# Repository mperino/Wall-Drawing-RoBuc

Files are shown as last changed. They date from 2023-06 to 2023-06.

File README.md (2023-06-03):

# Wall Drawing RoBuc

For FRC 2023-24 "Crescendo", I want to make a wall drawing robot that is capable of using both a marker and a spray can to make art live.  3D printed, read from SD card, powerfull steppers, stepper based pen (not servo) and with LED status lights to tell what color marker to load next.  My implementation is based on Fumik Robot, with a re-design of the Robot platform.  First Version will be a modified version of the Fumik code, with later versions being a complete re-write.
<br>
New Hardware Design:
https://a360.co/45KpkjN
<br>
<p>Front:
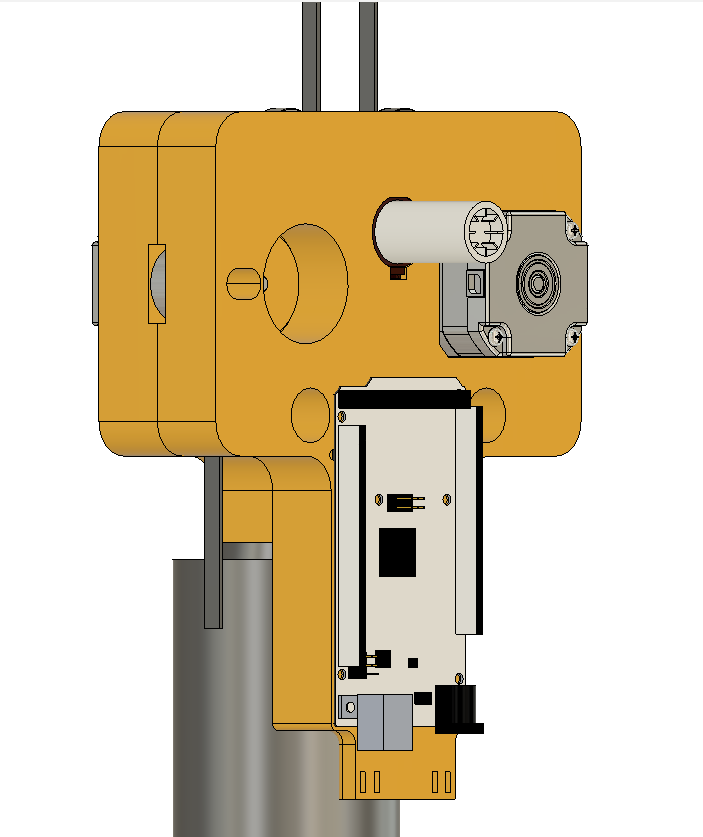
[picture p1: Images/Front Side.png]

</p>
<p>Back:
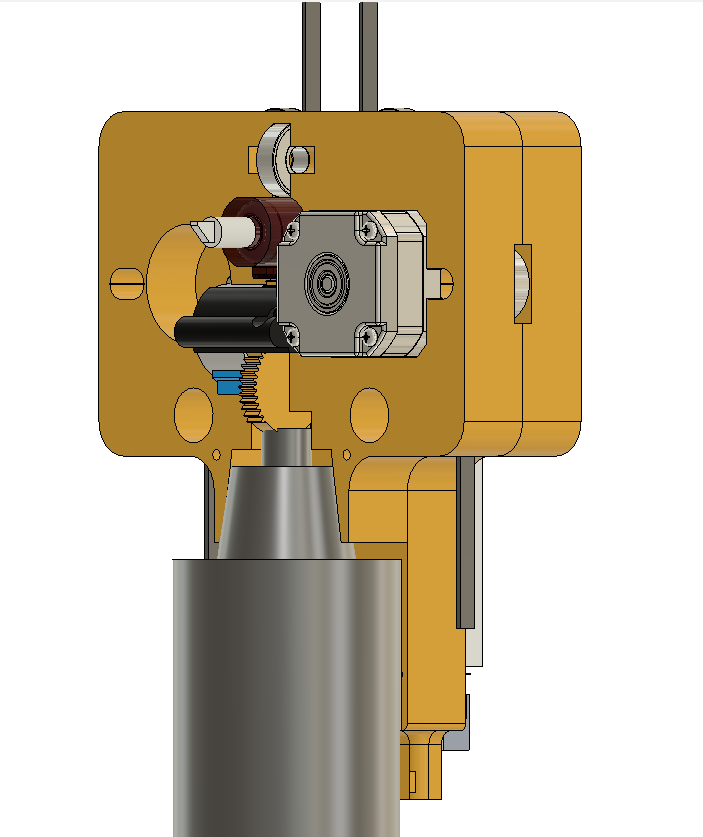
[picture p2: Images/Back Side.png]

</p>
<p> Inside:
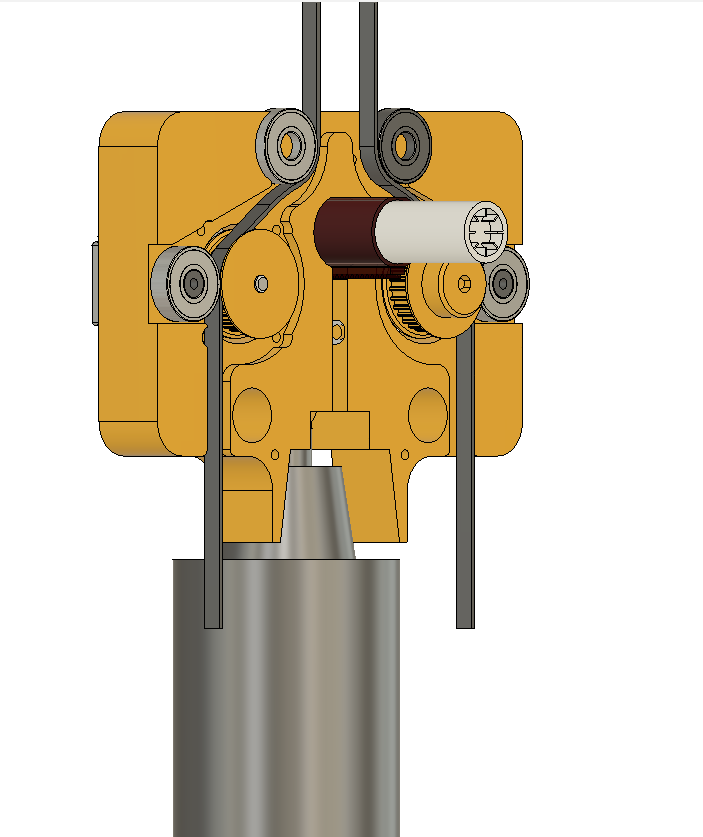
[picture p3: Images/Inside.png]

</p>
<br>

<br>
<hr>
The orignal Fumik code and instructions:
Visit the original Fumik at https://www.fumik.com/ 
<BR>
Fumik Arduino code for robot is at: https://github.com/fumikrobot/source-code/blob/main/fumik_rv9.ino
<p align="center">
  
</p>
<u><b> How to start a picture: </b></u>
<br/>
3.1 Your Picture need to draw
3.2 Convert picture to vector (*.svg file) by CorelDraw (or any other software support *.svg file)
<br/>
(see sample file test.cdr -> test.svg at https://github.com/fumikrobot/source-code/tree/main/draw%20file%20prepare)

3.3 Convert vector file to code for Arduino (by MS Excel, download at https://github.com/fumikrobot/source-code/blob/main/draw%20file%20prepare/SVG%20code%20extract.xlsm)

3.4 Copy code file to SD card
(sample file draw.txt at https://github.com/fumikrobot/source-code/blob/main/draw%20file%20prepare/draw.txt)

3.5 Plug in SD card to robot and start drawing
<br/><br/><br/><br/>
You can support and purchase the original at:
The robot can help us to make drawing on wall for fun or decoration. You can use robot as gift or STEM KIT for education for your kid, or student, hobbies need to understand about wall drawing robot.
<br/><br/>
Crowfunding at https://igg.me/at/fumik-robot
<br/>

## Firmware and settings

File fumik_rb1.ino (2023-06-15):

//Wall drawing RoBuc 
//Based on code from fumik.com - mail baank83@gmail.com
//Original Author: Nguyen Huu Phuc - 2022/May. All rights reserved.
//Wall RoBuc by Mark Perino mark.perino@gmail.com
//This code for Arduino MEGA, SD card

// Version 0.1, Code Status (partially working)
// LED code works
// M150 Rxxx Gxxx Bxxx Ixxx added
// Code Mode Switches work
// interactive works with move_pen_abs()


#include <AccelStepper.h>
#include <SD.h>                 // for SD card
#define SD_ChipSelectPin 53     // for SD card
File myFile;                    // for SD card
#include <Servo.h>              // for servo pen              
Servo pen_servo;               // for servo pen
#include <Adafruit_NeoPixel.h> // for neopixel ring
#define LED_PIN   49
// How many NeoPixels are attached to the Arduino?
#define LED_COUNT 12
// Declare our NeoPixel strip object:
Adafruit_NeoPixel strip(LED_COUNT, LED_PIN, NEO_GRB + NEO_KHZ800);

//how long to debounce]
#define DEBOUNCE_SLEEP

// Code Mode Switches
// 2 wired switches control the starting mode of the robot.
// First switch controls the command_mode: GCODE (new limitied) or FUNCTION COMMAND (original drawing mode)
// Secong switch controls if the action_mode is INTERACTIVE(new serial like grbl) or FILE (read draw.txt or draw.gcode)
#define COMMAND_MODE_PIN 45
#define ACTION_MODE_PIN 47
int command_state = 0;
int action_state = 0;
//stepper based PEN settings
//define Pen Load and Unload switches (Momentary Buttons)
#define PEN_LOAD_PIN 43
#define PEN_UNLOAD_PIN 42
#define PEN_LOAD_DISTANCE 100
#define PEN_UNLOAD_DISTANCE 200
int pen_load_state = 1;


const int dirPin_c = 7;
const int stepPin_c = 4;
const int dirPin_a = 5;
const int stepPin_a = 2;
const int dirPin_p = 6;   //drive for pen
const int stepPin_p = 3;  //drive for pen
const int enPin = 8;
#define motorInterfaceType 1

AccelStepper stepper_a(motorInterfaceType, stepPin_a, dirPin_a);
AccelStepper stepper_c(motorInterfaceType, stepPin_c, dirPin_c);
AccelStepper stepper_p(motorInterfaceType, stepPin_p, dirPin_p);

long steps_a, steps_c; //curent step of a, c
float a, c, a_0, c_0; //unit mm
float a_dev, c_dev; //deviation value of a, c
float pen_x, pen_y; //coordinate of pen, unit mm
float s_a, s_c, s_a_run, s_c_run; //steps for a, c
float pen_x0, pen_y0, pen_x0_next, pen_y0_next, svg_x0, svg_y0;
float x_ratio, y_ratio, x_angle, y_angle;
float draw_res; //draw resolution
float w2y, p;

float g1, g2, step1, step2, r1, r2;
float stepper_speed, basic_speed, by_stepper_speed;

boolean pen_pos;  //false = pen at open position; true = pen at write position

String draw_command;

void setup() {
  // setup Serial Port 
  Serial.begin(9600);
  
  // setup Pixel Ring
  Serial.println("Clearing LED Ring");
  strip.begin();
  strip.show(); // Initialize all pixels to 'off'
  strip.setPixelColor(1, 0, 50, 0);
  strip.show(); // set green pixel status
  
  // setup servos and motion parameters
  pen_servo.attach (11); //servo motor is connected to pin 11 Arduino Mega ~ (Z+ End Stop) of Arduino cnc Shield
  pinMode(enPin, OUTPUT);
  stepper_speed = 250; //unit steps/sec for main steppers
  by_stepper_speed = 250; //unit steps /sec for BY stepper
  basic_speed = 250;   //unit steps/sec; note: high speed + low resolution (draw_res) will make vibration
  stepper_a.setMaxSpeed(2000);
  stepper_a.setAcceleration(200000);  //set to max
  stepper_a.setSpeed(stepper_speed);
  
  stepper_c.setMaxSpeed(2000);
  stepper_c.setAcceleration(200000);  //set to max
  stepper_c.setSpeed(stepper_speed);

  stepper_p.setMaxSpeed(2000); //max 550
  stepper_p.setAcceleration(200000);
  stepper_p.setSpeed(by_stepper_speed);

  g1 = 63.68; //gear ratio
  g2 = g1;
  step1 = 32; //step/rev (full-step mode: 32; half-step mode: 64)
  step2 = step1;
  r1 = 9.5; //radius of wheel mm
  r2 = 9.5;
  a = 0;
  c = 0;

  p = 3190;   //mm, distance pin_a to pin_c (horizontal direction) 1600
  w2y = 40;  //mm, distance pin_a to pin_c (vertical direction)  4
 
  // zero position of pen must be same as in real model
  pen_x0 = 400;  //mm, computer room: 390-400-310
  pen_y0 = 700;  //mm, computer room: 900-700-410
                 //y0 under real -> C-curve up (u)
                 //y0 over real -> C-curve down (n)

  x_ratio = 1.0;  //adjust to change ratio of picture in x_axis
  y_ratio = 1.0;  //adjust to change ratio of picture in y_axis

  draw_res = 0.7; //mm, draw resolution is 0.7mm (high number -> high draw speed + low resolution)

  x_angle = -1.43; //degree, effect to rotation of picture in x_axis
  x_angle = radians(x_angle);

  y_angle = -0.36;  //degree, effect to rotation of picture in y_axis
  y_angle = radians(y_angle);

  pen_servo.write(50);  //set pen at open position, to make sure pen at open position
  pen_pos = false;      //now pen at open position, init pen_pos = "false"


  // which modes are we in Function Command vs Gcode, and INteractive vs. File
  pinMode(COMMAND_MODE_PIN, INPUT); // set defined pins to input
  pinMode(ACTION_MODE_PIN, INPUT); // set defined pins to input
  command_state = digitalRead(COMMAND_MODE_PIN);
  action_state = digitalRead(ACTION_MODE_PIN);
  if (command_state == HIGH) {
    Serial.println("Command Mode is GCODE");
    strip.setPixelColor(2, 0, 50, 0);
    strip.show(); // set pixel 2 to green aka gcode
  }
  else {
    Serial.println("Command Mode is Function Command. Aka original");
    strip.setPixelColor(2, 254, 119, 254);
    strip.show(); // set pixel 2 to Fuscia aka Function
  }
  if (action_state == HIGH) {
    Serial.println("Action Mode is Interactive");
    strip.setPixelColor(3, 5, 0, 50);
    strip.show(); // set pixel 3 to Indigo aka Interactive
  }
  else {
    Serial.println("Action Mode is File. draw.txt or draw.gcode will be used");
    strip.setPixelColor(3, 254, 119, 254);
    strip.show(); // set pixel 3 to Fuscia aka File
  }
  if (action_state == LOW) {
    // check if SD card mounted or not
    if (!SD.begin(SD_ChipSelectPin)) {  // see if the card is present and can be initialized:
      Serial.println("SD fail");
      return;   // don't do anything more if not
    }
    else{   
      Serial.println("---------------------------->>>>>>>-------SD card ok");
    }
    delay(200);
    myFile = SD.open("draw.txt");
    if (myFile) Serial.println("the file is opened OK");
    else Serial.println("error opening draw.txt");
  }
  else {
    Serial.println("Interactive Mode Setup.  Press Any Key to continue.");
    while (Serial.available() == 0) {
          }
    Serial.println("Entering Command Loop..");
  }
delay(10000);

}

void loop() {
    digitalWrite(enPin, LOW);  //enable stepper motor
    
    pen_write_pos();
    delay(1000);
    pen_open_pos();
    delay(1000);
          
    svg_x0 = 0;
    svg_y0 = 0;
  
    // declare a_0, c_0 at x0,y0
    find_a_c(pen_x0, pen_y0);
    a_0 = a;  //zero position
    c_0 = c;  //zero position
  
    pen_x0_next = pen_x0;
    pen_y0_next = pen_y0;

    while (action_state == HIGH) {
      Serial.println("Your Command?: ");
      while (Serial.available() == 0) {   
      }
      draw_command = Serial.readString();
      draw_command.trim();
      execute_command(draw_command);
    }

    // Reading the file
    String draw_command, string_result;
    char char_temp = '0';

    myFile = SD.open("draw.txt");

    // variables for draw
    float x1, x2, x3, x4, y1, y2, y3, y4;

    while(1){
      if (myFile) draw_command = read_until('(');
      else  Serial.println("error opening draw.txt");
  
      if (draw_command == "move_pen_abs("){
        string_result = read_until(',');  //continue reading file unit character ','
        string_result = string_result.substring(0,string_result.length()-1);  //will delete last character, it is ','
        x1 = string_result.toFloat();
        string_result = read_until(')');  //continue reading file unit character ')'
        string_result = string_result.substring(0,string_result.length()-1);  //will delete last character, it is ')'
        y1 = string_result.toFloat();
        move_pen_abs(x1,y1);  //move pen absolute to x1,y1
  
        //Serial.println(draw_command);
        //Serial.println(x1);
        //Serial.println(y1);
      }
      
      if (draw_command == "draw_curve("){
        string_result = read_until(',');  //continue reading file unit character ','
        string_result = string_result.substring(0,string_result.length()-1);  //will delete last character, it is ','
        x1 = string_result.toFloat();
        string_result = read_until(',');  //continue reading file unit character ')'
        string_result = string_result.substring(0,string_result.length()-1);  //will delete last character, it is ')'
        y1 = string_result.toFloat();
  
        string_result = read_until(',');  //continue reading file unit character ','
        string_result = string_result.substring(0,string_result.length()-1);  //will delete last character, it is ','
        x2 = string_result.toFloat();
        string_result = read_until(',');  //continue reading file unit character ')'
        string_result = string_result.substring(0,string_result.length()-1);  //will delete last character, it is ')'
        y2 = string_result.toFloat();
  
        string_result = read_until(',');  //continue reading file unit character ','
        string_result = string_result.substring(0,string_result.length()-1);  //will delete last character, it is ','
        x3 = string_result.toFloat();
        string_result = read_until(',');  //continue reading file unit character ')'
        string_result = string_result.substring(0,string_result.length()-1);  //will delete last character, it is ')'
        y3 = string_result.toFloat();
  
        string_result = read_until(',');  //continue reading file unit character ','
        string_result = string_result.substring(0,string_result.length()-1);  //will delete last character, it is ','
        x4 = string_result.toFloat();
        string_result = read_until(')');  //continue reading file unit character ')'
        string_result = string_result.substring(0,string_result.length()-1);  //will delete last character, it is ')'
        y4 = string_result.toFloat();
  
        draw_curve(x1,y1,x2,y2,x3,y3,x4,y4);
        /*
        Serial.println(draw_command);
        Serial.println(x1);
        Serial.println(y1);
        Serial.println(x2);
        Serial.println(y2);
        Serial.println(x3);
        Serial.println(y3);
        Serial.println(x4);
        Serial.println(y4);
        */
      }
  
      if (draw_command == "draw_line("){
        string_result = read_until(',');  //continue reading file unit character ','
        string_result = string_result.substring(0,string_result.length()-1);  //will delete last character, it is ','
        x1 = string_result.toFloat();
        string_result = read_until(',');  //continue reading file unit character ')'
        string_result = string_result.substring(0,string_result.length()-1);  //will delete last character, it is ')'
        y1 = string_result.toFloat();
  
        string_result = read_until(',');  //continue reading file unit character ','
        string_result = string_result.substring(0,string_result.length()-1);  //will delete last character, it is ','
        x2 = string_result.toFloat();
        string_result = read_until(')');  //continue reading file unit character ')'
        string_result = string_result.substring(0,string_result.length()-1);  //will delete last character, it is ')'
        y2 = string_result.toFloat();
  
        draw_line(x1,y1,x2,y2);
        //Serial.println(draw_command);
        //Serial.println(x1);
        //Serial.println(y1);
        //Serial.println(x2);
        //Serial.println(y2);
      }
  
      if (draw_command == "move_pen_rel("){
        string_result = read_until(',');  //continue reading file unit character ','
        string_result = string_result.substring(0,string_result.length()-1);  //will delete last character, it is ','
        x1 = string_result.toFloat();
        string_result = read_until(')');  //continue reading file unit character ')'
        string_result = string_result.substring(0,string_result.length()-1);  //will delete last character, it is ')'
        y1 = string_result.toFloat();
  
        move_pen_rel(x1,y1);
        //Serial.println(draw_command);
        //Serial.println(x1);
        //Serial.println(y1);
      }
  
      if (draw_command == "endfile(")  break;
  
      
      for (int i=0;i<3;i++){
        myFile.read();  //go through letter ';' and new line -> next reading is next command
      }
    }

  return_home();
  while(1){
    //stop here
    delay(5000);
    //digitalWrite(enPin, HIGH);  //un-enable stepper motor
  }
}


//======================================================SUB PROGRAM====================================
void execute_command(String draw_command) {
  // variables for draw
  float x1, y1, x2, y2;
  if (draw_command.startsWith("move_pen_abs")){
    String values = draw_command.substring(draw_command.indexOf("\(")+1, draw_command.indexOf("\)"));
    String x1v = values.substring(0,values.indexOf(","));
    x1 = x1v.toFloat();
    String y1v = values.substring(values.indexOf(",")+1,values.length());
    y1 = y1v.toFloat();
    move_pen_abs(x1,y1);  //move pen absolute to x1,y1
  //  Serial.println(draw_command);
  //  Serial.println(x1);
  //  Serial.println(y1);
  }

  if (draw_command.startsWith("endfile")){
    Serial.println("Reached File End");
  }

  if (draw_command.startsWith("draw_line")){
    String values = draw_command.substring(draw_command.indexOf("\(")+1, draw_command.indexOf("\)"));
    String x1v = values.substring(0,values.indexOf(","));
    x1 = x1v.toFloat();
    values = values.substring(",");
    String y1v = values.substring(0,values.indexOf(","));
    y1 = y1v.toFloat();
    values = values.substring(",");
    String x2v = values.substring(0,values.indexOf(","));
    x2 = x2v.toFloat();
    values = values.substring(",");
    String y2v = values.substring(0,values.indexOf(","));
    y2 = y2v.toFloat();
    Serial.println(draw_command);
    Serial.println(x1);
    Serial.println(y1);
    Serial.println(x2);
    Serial.println(y2);
    draw_line(x1,y1,x2,y2);  //move pen absolute to x1,y1
  }

  if (draw_command.startsWith("draw_curve")){
    String values = draw_command.substring(draw_command.indexOf("\(")+1, draw_command.indexOf("\)"));
    String pv = values.substring(0,values.indexOf(","));
    float p0x = pv.toFloat();
    values = values.substring(",");
    pv = values.substring(0,values.indexOf(","));
    float p0y = pv.toFloat();
    values = values.substring(",");
    pv = values.substring(0,values.indexOf(","));
    float p1x = pv.toFloat();
    values = values.substring(",");
    pv = values.substring(0,values.indexOf(","));
    float p1y = pv.toFloat();
    values = values.substring(",");
    pv = values.substring(0,values.indexOf(","));
    float p2x = pv.toFloat();
    values = values.substring(",");
    pv = values.substring(0,values.indexOf(","));
    float p2y = pv.toFloat();
    values = values.substring(",");
    pv = values.substring(0,values.indexOf(","));
    float p3x = pv.toFloat();
    values = values.substring(",");
    pv = values.substring(0,values.indexOf(","));
    float p3y = pv.toFloat();
    Serial.println(draw_command);
    Serial.println(p0x);
    Serial.println(p0y);
    Serial.println(p1x);
    Serial.println(p1y);
    Serial.println(p2x);
    Serial.println(p2y);
    Serial.println(p3x);
    Serial.println(p3y);
    draw_curve(p0x, p0y, p1x, p1y, p2x, p2y, p3x, p3y);  //draw the curve
  }

  if (draw_command.startsWith("set_home")){
    String values = draw_command.substring(draw_command.indexOf("\(")+1, draw_command.indexOf("\)"));
    String x1v = values.substring(0,values.indexOf(","));
    x1 = x1v.toInt();
    values = values.substring(",");
    String y1v = values.substring(0,values.indexOf(","));
    y1 = y1v.toInt();
    Serial.println(draw_command);
    Serial.println(x1);
    Serial.println(y1);
    set_home(x1,y1);  //Set Starting Co-ordinate
  }

  if (draw_command.startsWith("set_box_size")){
    String values = draw_command.substring(draw_command.indexOf("\(")+1, draw_command.indexOf("\)"));
    String x1v = values.substring(0,values.indexOf(","));
    x1 = x1v.toInt();
    values = values.substring(",");
    String y1v = values.substring(0,values.indexOf(","));
    y1 = y1v.toInt();
    Serial.println(draw_command);
    Serial.println(x1);
    Serial.println(y1);
    set_box_size(x1,y1);  //Set Starting Co-ordinate
  }

  if (draw_command.startsWith("M150")){
    String values = draw_command.substring(draw_command.indexOf("\(")+1, draw_command.indexOf("\)"));
    String rs = values.substring(values.indexOf("R")+1);
    rs = rs.substring(0,rs.indexOf(" "));
    int red = rs.toInt();
    String gr = values.substring(values.indexOf("G")+1);
    gr = gr.substring(0,gr.indexOf(" "));
    int green = gr.toInt();
    String bl = values.substring(values.indexOf("B")+1);
    bl = bl.substring(0,gr.indexOf(" "));
    int blue = bl.toInt();
    String pi = values.substring(values.indexOf("I")+1);
    pi = pi.substring(0,gr.indexOf(" "));
    int pixel = pi.toInt();
    set_rgb_color(pixel, red, green, blue);

  //  Serial.println(draw_command);
  //  Serial.println(x1);
  //  Serial.println(y1);
  }
}
void set_rgb_color(int pixel, int red, int green, int blue){
  strip.setPixelColor(pixel, red, green, blue);
  strip.show();
}

void set_ring_color(int pixels, int r, int g, int b){
  for (int pix =0; pix <= pixels; pix++) {
    set_rgb_color(pix, r, g, b);
  }
}

void set_box_size(int wide, int tall){
  p = wide;   //mm, distance pin_a to pin_c (horizontal direction) 1600
  w2y = tall;  //mm, distance pin_a to pin_c (vertical direction)  4
}

void set_home(int x0, int y0){
  pen_x0 = x0;  //mm
  pen_y0 = y0;  //mm
}

void change_pen(int R, int G, int, int B){
  //unload Pen
  //loop
  set_ring_color(LED_COUNT,R,G,B);
  // check input
  // debounce
}

void move_a_c(float s1, float s2){
  int stepper_a_speed, stepper_c_speed; //unit steps/sec

  // Set the current position to 0:
  stepper_a.setCurrentPosition(0);
  stepper_c.setCurrentPosition(0);
  
  if(abs(s1)>=abs(s2)){
    if(s1<0) {stepper_a_speed = basic_speed;} //speed pos: motor a makes robot move up
    else stepper_a_speed = -basic_speed;      //speed neg: motor a makes robot move down

    if(s2<0) {stepper_c_speed = -abs(s2/s1)*basic_speed;}  //speed pos: motor c makes robot move down
    else stepper_c_speed = abs(s2/s1)*basic_speed;         //speed neg: motor c makes robot move up
  }
  else{
    if(s2<0) {stepper_c_speed = -basic_speed;}  //speed pos: motor c makes robot move down
    else stepper_c_speed = basic_speed;         //speed neg: motor c makes robot move up

    if(s1<0) {stepper_a_speed = abs(s1/s2)*basic_speed;}    //speed pos: motor a makes robot move up
    else stepper_a_speed = -abs(s1/s2)*basic_speed;         //speed neg: motor a makes robot move down
  }


  if (abs(stepper_a_speed) < 5){
    if (stepper_a_speed < 0) stepper_a_speed = -5;
    else stepper_a_speed = 5;
  }
  if (abs(stepper_c_speed) < 5){
    if (stepper_c_speed < 0) stepper_c_speed = -5;
    else stepper_c_speed = 5;
  }
  /*

  Serial.print("stepper_a_speed = ");
  Serial.println(stepper_a_speed);
  Serial.print("stepper_c_speed = ");
  Serial.println(stepper_c_speed);
  Serial.print("s1 = ");
  Serial.println(s1);
  Serial.print("s2 = ");
  Serial.println(s2);
  */
  

  // Run the motor
  while((abs(stepper_a.currentPosition()) < abs((long)s1))||(abs(stepper_c.currentPosition()) < abs((long)s2)))
  {
    stepper_a.setSpeed(stepper_a_speed); //speed pos: motor a makes robot move up; 
    if((abs(stepper_a.currentPosition()) < abs((long)s1))) {stepper_a.runSpeed();}
    
    stepper_c.setSpeed(stepper_c_speed); //speed pos: motor c makes robot move down
    if((abs(stepper_c.currentPosition()) < abs((long)s2))) {stepper_c.runSpeed();}
  }
  steps_a += -stepper_a.currentPosition();
  steps_c += stepper_c.currentPosition();

  
  Serial.print("steps_a = ");
  Serial.println(steps_a);
  Serial.print("steps_c = ");
  Serial.println(steps_c);
  
  
  
}
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

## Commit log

2023-06-01 Add files via upload
    Version 0.1 Added switches and lights.
2023-06-01 Add files via upload
    images of assembly
2023-06-24 Add files via upload
    PCB for fabrication
    [wallbot with screen-wiring-nr.fzz]
